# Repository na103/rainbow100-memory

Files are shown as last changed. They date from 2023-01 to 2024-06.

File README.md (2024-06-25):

# Rainbow 100B memory extension
this is a remake of RAM expansion board for [Digital Rainbow 100](https://en.wikipedia.org/wiki/Rainbow_100) rev B<br>

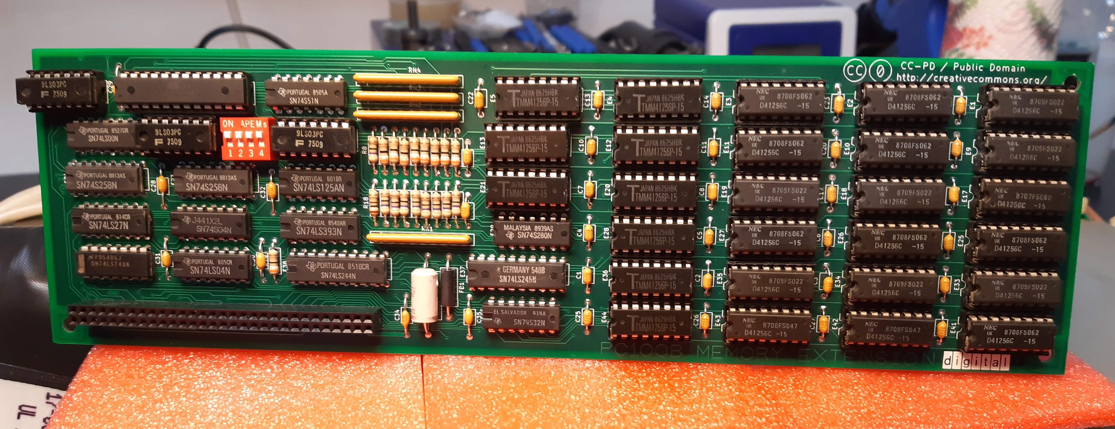
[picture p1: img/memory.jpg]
memory extension


This expansion board it can reach up to 896Kb of RAM. differently to 8088 XT PCs, Rainbow 100 architecture is not limited at 640Kb of memory.<br>
Kicad schematics is derived from [Tony Duell's notes](https://github.com/na103/rainbow100-memory/blob/main/docs/Duell_ram_expansion.pdf) and at the end verified with [original DEC schematics](https://github.com/na103/rainbow100-memory/tree/main/docs/Dec).<br>
95% of the components and traces have been rebuilt respecting the original position; only the bipolar Prom E7 whos entrusted control logic for the memory banks switch has been replaced with a extra large GAL22V10.

## Bill of materials
| Qt. | Description | Designator | Mouser Part | Note |
|:---:|---|---|---|---|
|27 |Cap. 220 nF 50V |C1 -C27 |C430C224Z5U5TA | |
|1 |Cap. 10uF 35V |C33 |MAL213831109E3 | |
|5 |Cap. 47nF 50V |C28 - C32 |C410C473Z5U5TA | |
|2 |Cap. 10nF 50V |C34 C35 |C410C103Z5U5TA | |
|1 |Bead Ferrite |FB1 |2743002112 | |
|1 |Rnet 9x470Ω 10 pin  |RN4 |4610X-101-471LF | |
|2 |Rnet 9x1kΩ 10 pin |RN3 RN2 |4610X-101-102LF | |
|1 |Rnet 9x4.7kΩ 10 pin |RN1 |4610X-AP1-472LF | |
|9 |R 39Ω |R10 - R17 R19 |CFR-25JB-52-39R | |
|1 |R 100Ω |R18 |CFR-25JT-52-100R | |
|9 |R 47Ω |R1 - R9 |CFR-25JB-52-47R | |
|1 |Switch DIP 4POS |SW1 |78RB04ST | |
|1 |025X025 REC 2X30P |J1 |5-102766-4 | |
|27 |16P DIP SKT |E1-E5 E9-E13 E17-E21 E25-E28 |1-2199298-4 | |
| | |E33-E36 E41-E44 | | |
|1 |24P DIP SKT |E7 |1-2199298-8 | optional, useful for testing  |
|1 |GAL 22V10 |E7 |ATF22V10C-15PU | need programmer like TL866 |
|3 |74S03N |E8 E14 E15 |SN74LS03N | |
|1 |74LS00N |E16 |SN74LS00N | |
|2 |74S258N |E23 E24 |SN74LS258N | |
|1 |74LS27N |E32 |SN74LS27N | |
|1 |74LS74AN |E40 |SN74LS74AN | |
|2 |74LS04N |E31 E39 |SN74LS04N | |
|1 |74S51N |E6 |SN74LS51N | |
|1 |74LS125AN |E22 |SN74LS125AN | |
|1 |74LS393N |E30 |SN74LS393N | |
|1 |74LS244N |E38 |SN74LS244N | |
|1 |74S280N |E29 |SN74LS280N | |
|1 |74LS245N |E37 |SN74LS245N | |
|1 |74S32N |E45 |SN74LS32N | |
|27 |DRAM 41256-15 or |E1-E5 E9-13 E17-E21 E25-E28 | | from ebay or [utsource](https://www.utsource.net)|
| |4164-15 max 150ns |E33-E36 E41-E44 | | |
<br><br>
## Memory dip switch set-up

The DIP switches are to be set according to how many banks are populated and with kind of DRAM chip (256kb or 64kb).

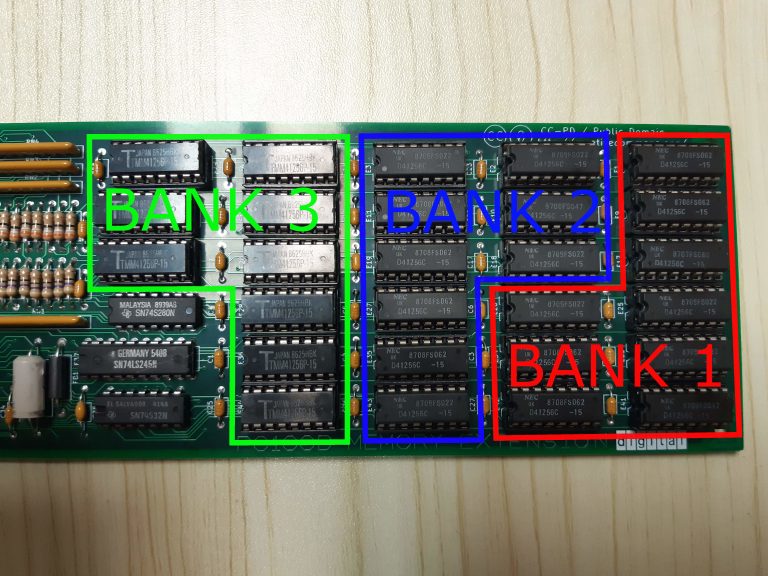
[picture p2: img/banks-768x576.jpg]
banks position


| Dip 1-2-3-4 | bank1 | bank2 | bank3 |
|:---:|---|---|---|
| off off off on | 64K | | |
| off off off on | 64K | 64K | |
| off off off on | 64K | 64K | 64K |
| on  off off on | 256K | 64K or empty | 64K or empty |
| on  on  off on | 256K | 256K | 64K or empty |
| on  on  on  on | 256K | 256K | 256K |

## Building notes

due to the E7 larger size all memory banks are closer to the edge of the board, the two plastic supports need to be filed slightly to get them into their seat
<br>

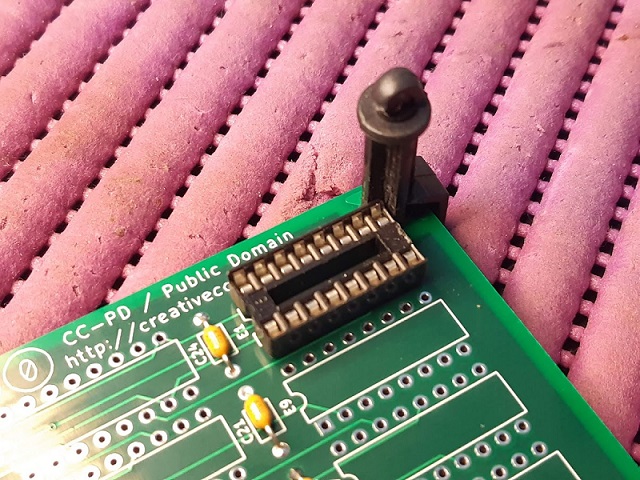
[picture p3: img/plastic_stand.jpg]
stand support

<br>

If you found this my work useful, please consider buying me a cup of coffee if you want:<br>


# License

This work is licensed under a Creative Commons Attribution 4.0 International License. See [https://creativecommons.org/licenses/by/4.0/](https://creativecommons.org/licenses/by/4.0/).

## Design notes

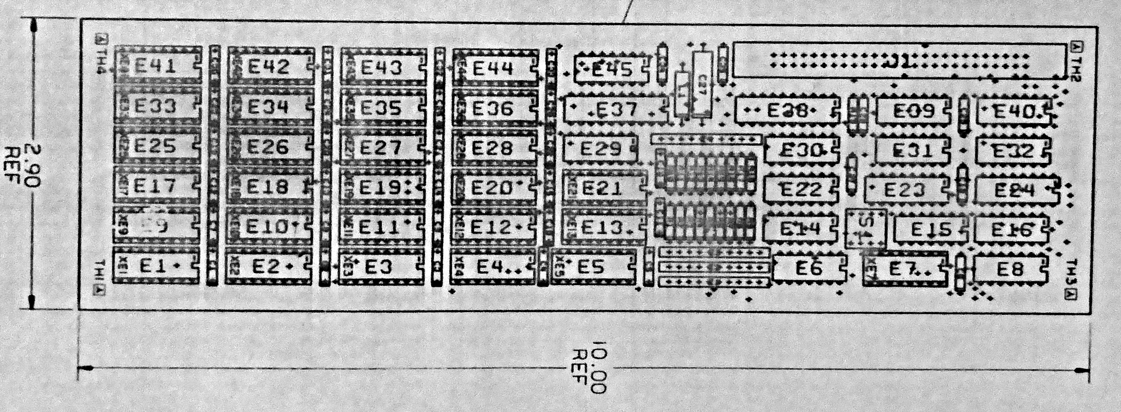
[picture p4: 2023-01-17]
docs/Dec/PC100Bmem 10a P1100113.JPG

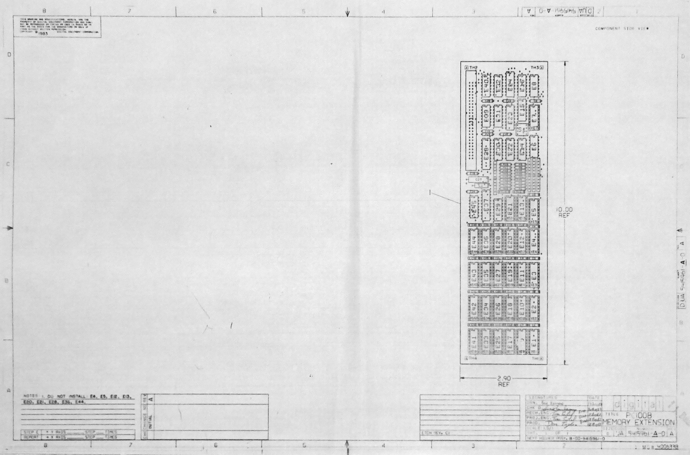
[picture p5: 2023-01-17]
docs/Dec/PC100Bmem 10 P1100112.JPG

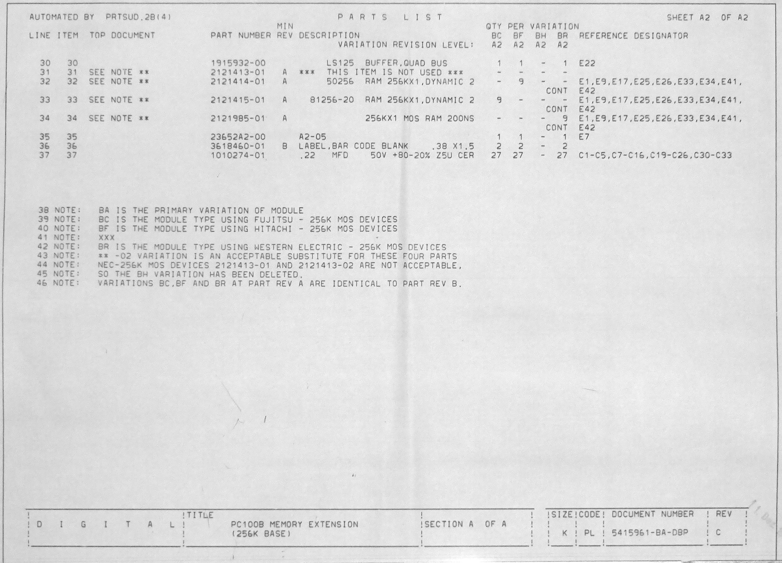
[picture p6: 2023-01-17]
docs/Dec/PC100Bmem 09 P1100109.JPG

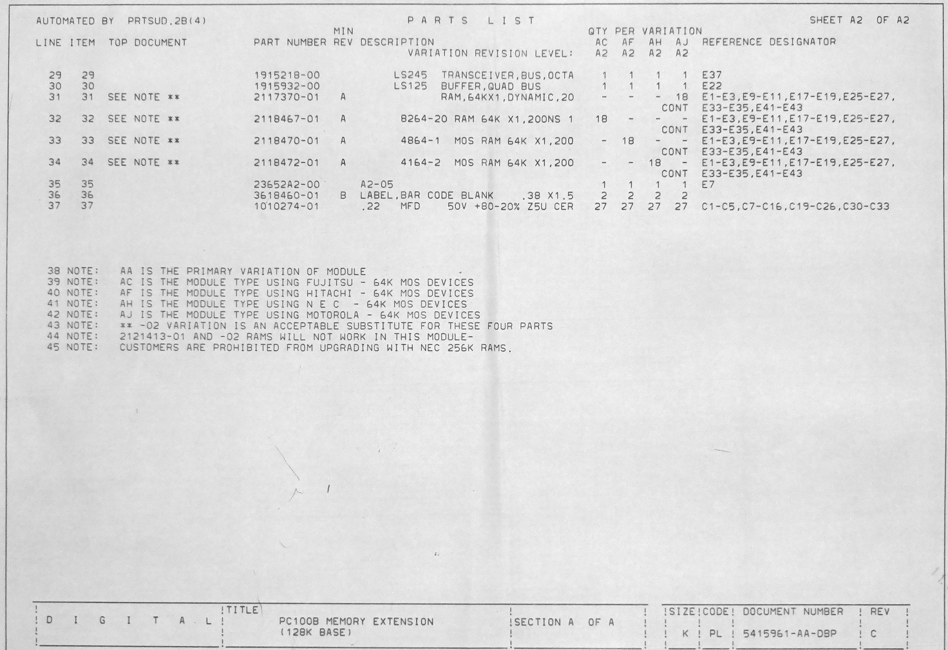
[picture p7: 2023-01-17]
docs/Dec/PC100Bmem 07 P1100106.JPG

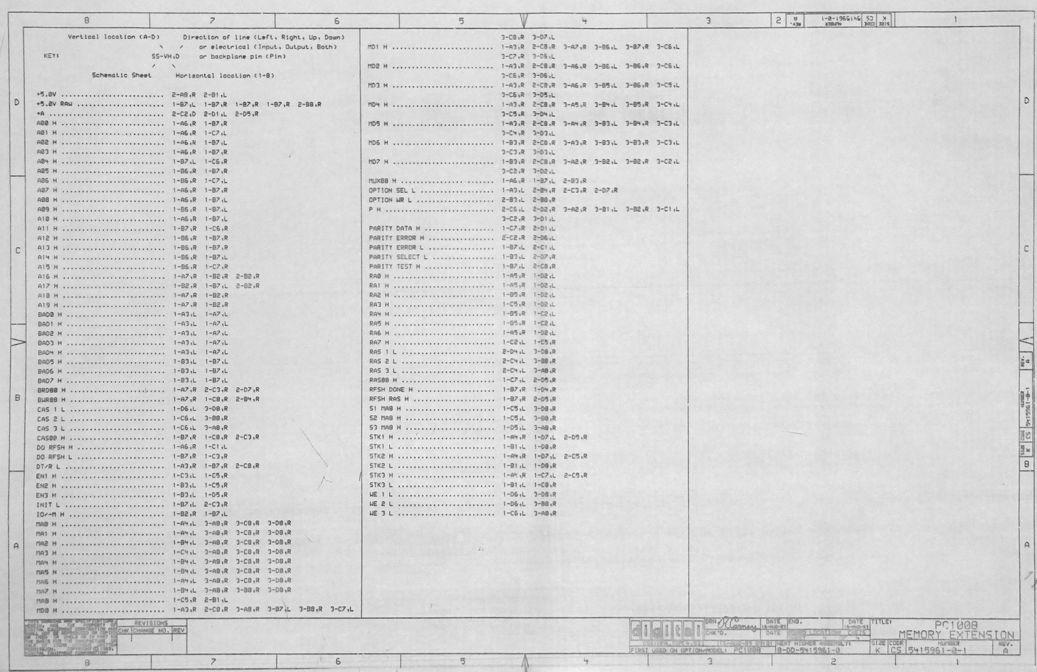
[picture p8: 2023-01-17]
docs/Dec/PC100Bmem 04 P1100098.JPG

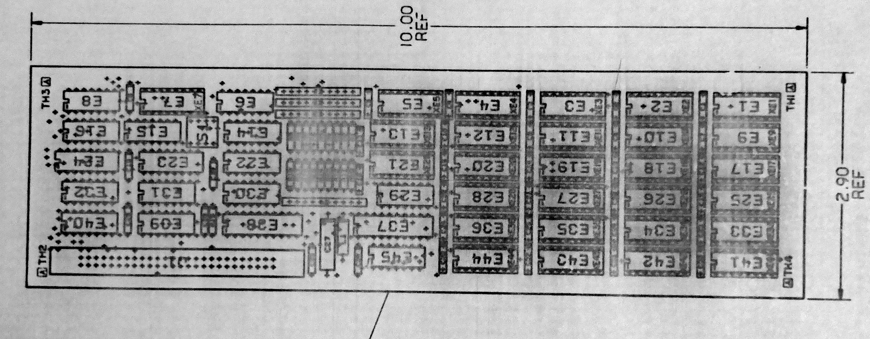
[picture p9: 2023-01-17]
docs/Dec/PC100Bmem 05a P1100102.JPG

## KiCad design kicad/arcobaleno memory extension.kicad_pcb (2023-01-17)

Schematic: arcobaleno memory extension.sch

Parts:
C1, C2, C3, C4, C5, C6, C7, C8, C9, C10, C11, C12, C13, C14, C15, C16, C17, C18, C19, C20, C21, C22, C23, C24, C25, C26, C27: 220nF; C_Axial_L3.8mm_D2.6mm_P7.50mm_Horizontal
C28, C29, C30, C31, C32: 47nF; C_Axial_L3.8mm_D2.6mm_P10.00mm_Horizontal
C33: 10uF; C_Axial_L12.0mm_D6.5mm_P20.00mm_Horizontal
C34, C35: 10nF; C_Axial_L3.8mm_D2.6mm_P10.00mm_Horizontal
E1, E2, E3, E4, E5, E9, E10, E11, E12, E13, E17, E18, E19, E20, E21, E25, E26, E27, E28, E33, E34, E35, E36, E41, E42, E43, E44: UPD41256C; DIP-16_W7.62mm; Manufacturer_Part_Number UPD41256C
E6: 74LS51; DIP-14_W7.62mm
E7: GAL22V10D-15LP; DIP-24_W7.62mm; Mouser Part Number 842-GAL22V10D15LP
E8, E14, E15: 74LS03; DIP-14_W7.62mm
E16: 74LS00; DIP-14_W7.62mm
E22: 74LS125; DIP-14_W7.62mm
E23, E24: 74LS258; DIP-16_W7.62mm
E29: 74LS280; DIP-14_W7.62mm
E30: 74LS393; DIP-14_W7.62mm
E31, E39: 74LS04; DIP-14_W7.62mm
E32: 74LS27; DIP-14_W7.62mm
E37: 74LS245; DIP-20_W7.62mm
E38: 74LS244; DIP-20_W7.62mm
E40: 74LS74; DIP-14_W7.62mm
E45: 74LS32; DIP-14_W7.62mm
FB1: 3 Omh 2.4 uH; L_Axial_L9.5mm_D4.0mm_P15.24mm_Horizontal_Fastron_SMCC
J1: SSW-126-01-T-D; SAMTEC_SSW-126-01-T-D; Mouser Part Number 200-SSW12601TD
R1, R2, R3, R4, R5, R6, R7, R8, R9: 47; R_Axial_DIN0207_L6.3mm_D2.5mm_P10.16mm_Horizontal
R10, R11, R12, R13, R14, R15, R16, R17, R19: 39; R_Axial_DIN0207_L6.3mm_D2.5mm_P10.16mm_Horizontal
R18: 100; R_Axial_DIN0207_L6.3mm_D2.5mm_P10.16mm_Horizontal
RN1: 4.7k; R_Array_SIP10
RN2, RN3: 1k; R_Array_SIP10
RN4: 470; R_Array_SIP10
SW1: SW_DIP_x04

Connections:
+5V: C1.2, C2.2, C3.2, C4.2, C5.2, C6.2, C7.2, C8.2, C9.2, C10.2, C11.2, C12.2, C13.2, C14.2, C15.2, C16.2, C17.2, C18.2, C19.2, C20.2, C21.2, C22.2, C23.2, C24.2, C25.2, C26.2, C27.2, C28.1, C29.1, C30.1, C31.1, C32.1, C33.1, C34.2, C35.1, E1.8 (VCC), E2.8 (VCC), E3.8 (VCC), E4.8 (VCC), E5.8 (VCC), E6.14 (VCC), E7.24 (VCC), E8.14 (VCC), E9.8 (VCC), E10.8 (VCC), E11.8 (VCC), E12.8 (VCC), E13.8 (VCC), E14.14 (VCC), E15.14 (VCC), E16.14 (VCC), E17.8 (VCC), E18.8 (VCC), E19.8 (VCC), E20.8 (VCC), E21.8 (VCC), E22.14 (VCC), E23.16 (VCC), E24.16 (VCC), E25.8 (VCC), E26.8 (VCC), E27.8 (VCC), E28.8 (VCC), E29.14 (VCC), E30.14 (VCC), E31.14 (VCC), E32.14 (VCC), E33.8 (VCC), E34.8 (VCC), E35.8 (VCC), E36.8 (VCC), E37.20 (VCC), E38.20 (VCC), E39.14 (VCC), E40.14 (VCC), E41.8 (VCC), E42.8 (VCC), E43.8 (VCC), E44.8 (VCC), E45.14 (VCC), FB1.1, FB1.2, J1.25, J1.27, J1.28, J1.35, RN1.1 (common), RN2.1 (R1.1), RN3.1 (R1.1), RN4.1 (R1.1)
/MUXA0: E23.12 (Zc), E38.18 (O0a), R17.2, RN2.3 (R2.2)
/MUXA1: E23.9 (Zd), E38.16 (O1a), R16.2, RN2.4 (R3.2)
/MUXA2: E23.4 (Za), E38.14 (O2a), R14.2, RN2.5 (R4.2)
/MUXA3: E24.4 (Za), E38.9 (O0b), R10.2, RN2.6 (R5.2)
/MUXA4: E24.12 (Zc), E38.3 (O3b), R13.2, RN2.7 (R6.2)
/MUXA5: E24.9 (Zd), E38.5 (O2b), R12.2, RN2.8 (R7.2)
/MUXA6: E23.7 (Zb), E38.12 (O3a), R15.2, RN2.9 (R8.2)
/MUXA7: E24.7 (Zb), E38.7 (O1b), R11.2, RN2.10 (R9.2)
/Rfsh0: E30.3 (Q0), E38.2 (I0a)
/Rfsh1: E30.4 (Q1), E38.4 (I1a)
/Rfsh2: E30.5 (Q2), E38.6 (I2a)
/Rfsh3: E30.6 (Q3), E30.13 (CP), E38.11 (I0b)
/Rfsh4: E30.11 (Q0), E38.17 (I3b)
/Rfsh5: E30.10 (Q1), E38.15 (I2b)
/Rfsh6: E30.9 (Q2), E38.8 (I3a)
/Rfsh7: E30.8 (Q3), E38.13 (I1b)
A0: E23.13 (I1c), J1.13
A1: E23.10 (I1d), J1.8
A2: E23.3 (I1a), J1.16
A3: E23.6 (I1b), J1.11
A4: E24.3 (I1a), J1.22
A5: E24.13 (I1c), J1.17
A6: E24.10 (I1d), J1.6
A7: E23.14 (I0c), J1.15
A8: E23.11 (I0d), J1.10
A9: E23.2 (I0a), J1.18
A10: E23.5 (I0b), J1.12
A11: E24.2 (I0a), J1.21
A12: E24.14 (I0c), J1.19
A13: E24.11 (I0d), J1.9
A14: E24.5 (I0b), J1.14
A15: E24.6 (I1b), J1.7
A16: E6.3, E7.9 (I_8), J1.47
A17: E6.5, E7.8 (I_7), J1.32
A18: E7.7 (I_6), J1.43
A19: E7.6 (I_5), J1.49, RN3.2 (R1.2)
AMUX: E6.2, E23.1 (S), E24.1 (S), E31.9, J1.20
CAS1: E1.15 (~CAS), E9.15 (~CAS), E17.15 (~CAS), E25.15 (~CAS), E26.15 (~CAS), E33.15 (~CAS), E34.15 (~CAS), E41.15 (~CAS), E42.15 (~CAS), R9.1
CAS2: E2.15 (~CAS), E3.15 (~CAS), E10.15 (~CAS), E11.15 (~CAS), E18.15 (~CAS), E19.15 (~CAS), E27.15 (~CAS), E35.15 (~CAS), E43.15 (~CAS), R2.1
CAS3: E4.15 (~CAS), E5.15 (~CAS), E12.15 (~CAS), E13.15 (~CAS), E20.15 (~CAS), E21.15 (~CAS), E28.15 (~CAS), E36.15 (~CAS), E44.15 (~CAS), R5.1
CASTime: E8.5, E8.13, E14.10, E16.4, J1.37
ClkParity: E22.8, E40.3 (C), E40.11 (C), RN3.6 (R5.2)
D0: E37.18 (B0), J1.50
D1: E37.17 (B1), J1.48
D2: E37.16 (B2), J1.46
D3: E37.15 (B3), J1.44
D4: E37.14 (B4), J1.42
D5: E37.13 (B5), J1.40
D6: E37.12 (B6), J1.38
D7: E37.11 (B7), J1.36
DRAMA0: E1.5 (A0), E2.5 (A0), E3.5 (A0), E4.5 (A0), E5.5 (A0), E9.5 (A0), E10.5 (A0), E11.5 (A0), E12.5 (A0), E13.5 (A0), E17.5 (A0), E18.5 (A0), E19.5 (A0), E20.5 (A0), E21.5 (A0), E25.5 (A0), E26.5 (A0), E27.5 (A0), E28.5 (A0), E33.5 (A0), E34.5 (A0), E35.5 (A0), E36.5 (A0), E41.5 (A0), E42.5 (A0), E43.5 (A0), E44.5 (A0), R17.1
DRAMA1: E1.7 (A1), E2.7 (A1), E3.7 (A1), E4.7 (A1), E5.7 (A1), E9.7 (A1), E10.7 (A1), E11.7 (A1), E12.7 (A1), E13.7 (A1), E17.7 (A1), E18.7 (A1), E19.7 (A1), E20.7 (A1), E21.7 (A1), E25.7 (A1), E26.7 (A1), E27.7 (A1), E28.7 (A1), E33.7 (A1), E34.7 (A1), E35.7 (A1), E36.7 (A1), E41.7 (A1), E42.7 (A1), E43.7 (A1), E44.7 (A1), R16.1
DRAMA2: E1.6 (A2), E2.6 (A2), E3.6 (A2), E4.6 (A2), E5.6 (A2), E9.6 (A2), E10.6 (A2), E11.6 (A2), E12.6 (A2), E13.6 (A2), E17.6 (A2), E18.6 (A2), E19.6 (A2), E20.6 (A2), E21.6 (A2), E25.6 (A2), E26.6 (A2), E27.6 (A2), E28.6 (A2), E33.6 (A2), E34.6 (A2), E35.6 (A2), E36.6 (A2), E41.6 (A2), E42.6 (A2), E43.6 (A2), E44.6 (A2), R14.1
DRAMA3: E1.12 (A3), E2.12 (A3), E3.12 (A3), E4.12 (A3), E5.12 (A3), E9.12 (A3), E10.12 (A3), E11.12 (A3), E12.12 (A3), E13.12 (A3), E17.12 (A3), E18.12 (A3), E19.12 (A3), E20.12 (A3), E21.12 (A3), E25.12 (A3), E26.12 (A3), E27.12 (A3), E28.12 (A3), E33.12 (A3), E34.12 (A3), E35.12 (A3), E36.12 (A3), E41.12 (A3), E42.12 (A3), E43.12 (A3), E44.12 (A3), R10.1
DRAMA4: E1.11 (A4), E2.11 (A4), E3.11 (A4), E4.11 (A4), E5.11 (A4), E9.11 (A4), E10.11 (A4), E11.11 (A4), E12.11 (A4), E13.11 (A4), E17.11 (A4), E18.11 (A4), E19.11 (A4), E20.11 (A4), E21.11 (A4), E25.11 (A4), E26.11 (A4), E27.11 (A4), E28.11 (A4), E33.11 (A4), E34.11 (A4), E35.11 (A4), E36.11 (A4), E41.11 (A4), E42.11 (A4), E43.11 (A4), E44.11 (A4), R13.1
DRAMA5: E1.10 (A5), E2.10 (A5), E3.10 (A5), E4.10 (A5), E5.10 (A5), E9.10 (A5), E10.10 (A5), E11.10 (A5), E12.10 (A5), E13.10 (A5), E17.10 (A5), E18.10 (A5), E19.10 (A5), E20.10 (A5), E21.10 (A5), E25.10 (A5), E26.10 (A5), E27.10 (A5), E28.10 (A5), E33.10 (A5), E34.10 (A5), E35.10 (A5), E36.10 (A5), E41.10 (A5), E42.10 (A5), E43.10 (A5), E44.10 (A5), R12.1
DRAMA6: E1.13 (A6), E2.13 (A6), E3.13 (A6), E4.13 (A6), E5.13 (A6), E9.13 (A6), E10.13 (A6), E11.13 (A6), E12.13 (A6), E13.13 (A6), E17.13 (A6), E18.13 (A6), E19.13 (A6), E20.13 (A6), E21.13 (A6), E25.13 (A6), E26.13 (A6), E27.13 (A6), E28.13 (A6), E33.13 (A6), E34.13 (A6), E35.13 (A6), E36.13 (A6), E41.13 (A6), E42.13 (A6), E43.13 (A6), E44.13 (A6), R15.1
DRAMA7: E1.9 (A7), E2.9 (A7), E3.9 (A7), E4.9 (A7), E5.9 (A7), E9.9 (A7), E10.9 (A7), E11.9 (A7), E12.9 (A7), E13.9 (A7), E17.9 (A7), E18.9 (A7), E19.9 (A7), E20.9 (A7), E21.9 (A7), E25.9 (A7), E26.9 (A7), E27.9 (A7), E28.9 (A7), E33.9 (A7), E34.9 (A7), E35.9 (A7), E36.9 (A7), E41.9 (A7), E42.9 (A7), E43.9 (A7), E44.9 (A7), R11.1
DRAMD0: E29.9 (B), E34.2 (DIN), E34.14 (DOUT), E35.2 (DIN), E35.14 (DOUT), E36.2 (DIN), E36.14 (DOUT), E37.2 (A0), RN1.3 (R2)
DRAMD1: E26.2 (DIN), E26.14 (DOUT), E27.2 (DIN), E27.14 (DOUT), E28.2 (DIN), E28.14 (DOUT), E29.10 (C), E37.3 (A1), RN1.4 (R3)
DRAMD2: E19.2 (DIN), E19.14 (DOUT), E20.2 (DIN), E20.14 (DOUT), E29.11 (D), E37.4 (A2), E41.2 (DIN), E41.14 (DOUT), RN1.5 (R4)
DRAMD3: E11.2 (DIN), E11.14 (DOUT), E12.2 (DIN), E12.14 (DOUT), E29.12 (E), E33.2 (DIN), E33.14 (DOUT), E37.5 (A3), RN1.6 (R5)
DRAMD4: E3.2 (DIN), E3.14 (DOUT), E4.2 (DIN), E4.14 (DOUT), E25.2 (DIN), E25.14 (DOUT), E29.13 (F), E37.6 (A4), RN1.7 (R6)
DRAMD5: E17.2 (DIN), E17.14 (DOUT), E18.2 (DIN), E18.14 (DOUT), E21.2 (DIN), E21.14 (DOUT), E29.1 (G), E37.7 (A5), RN1.8 (R7)
DRAMD6: E9.2 (DIN), E9.14 (DOUT), E10.2 (DIN), E10.14 (DOUT), E13.2 (DIN), E13.14 (DOUT), E29.2 (H), E37.8 (A6), RN1.9 (R8)
DRAMD7: E1.2 (DIN), E1.14 (DOUT), E2.2 (DIN), E2.14 (DOUT), E5.2 (DIN), E5.14 (DOUT), E29.4 (I), E37.9 (A7), RN1.10 (R9)
DRAMP: E22.3, E22.6, E32.13, E40.2 (D), E42.2 (DIN), E42.14 (DOUT), E43.2 (DIN), E43.14 (DOUT), E44.2 (DIN), E44.14 (DOUT), RN1.2 (R1)
GND: C1.1, C2.1, C3.1, C4.1, C5.1, C6.1, C7.1, C8.1, C9.1, C10.1, C11.1, C12.1, C13.1, C14.1, C15.1, C16.1, C17.1, C18.1, C19.1, C20.1, C21.1, C22.1, C23.1, C24.1, C25.1, C26.1, C27.1, C28.2, C29.2, C30.2, C31.2, C32.2, C33.2, C34.1, C35.2, E1.16 (GND), E2.16 (GND), E3.16 (GND), E4.16 (GND), E5.16 (GND), E6.7 (GND), E7.12 (GND), E8.7 (GND), E9.16 (GND), E10.16 (GND), E11.16 (GND), E12.16 (GND), E13.16 (GND), E14.7 (GND), E15.7 (GND), E16.7 (GND), E17.16 (GND), E18.16 (GND), E19.16 (GND), E20.16 (GND), E21.16 (GND), E22.7 (GND), E23.8 (GND), E24.8 (GND), E25.16 (GND), E26.16 (GND), E27.16 (GND), E28.16 (GND), E29.7 (GND), E30.7 (GND), E31.7 (GND), E32.7 (GND), E33.16 (GND), E34.16 (GND), E35.16 (GND), E36.16 (GND), E37.10 (GND), E38.10 (GND), E39.7 (GND), E40.7 (GND), E41.16 (GND), E42.16 (GND), E43.16 (GND), E44.16 (GND), E45.7 (GND), J1.1, J1.2, J1.3, J1.51, J1.52, R18.2, SW1.1, SW1.2, SW1.3, SW1.4
IO_M: E7.2 (I_1), J1.30
unnamed: E1.1 (A8), E9.1 (A8), E17.1 (A8), E25.1 (A8), E26.1 (A8), E33.1 (A8), E34.1 (A8), E41.1 (A8), E42.1 (A8), E45.8
unnamed: E6.6, R19.2, RN3.8 (R7.2)
unnamed: E8.3, R8.2, RN4.2 (R1.2)
unnamed: E8.6, R9.2, RN4.9 (R8.2)
unnamed: E8.8, R1.2, RN4.5 (R4.2)
unnamed: E8.11, R2.2, RN4.4 (R3.2)
unnamed: E2.1 (A8), E3.1 (A8), E10.1 (A8), E11.1 (A8), E18.1 (A8), E19.1 (A8), E27.1 (A8), E35.1 (A8), E43.1 (A8), E45.6
unnamed: E4.1 (A8), E5.1 (A8), E12.1 (A8), E13.1 (A8), E20.1 (A8), E21.1 (A8), E28.1 (A8), E36.1 (A8), E44.1 (A8), E45.3
unnamed: E14.3, E14.6, R4.2, RN4.7 (R6.2)
unnamed: E14.8, R5.2, RN4.8 (R7.2)
unnamed: E14.11, R6.2, RN4.10 (R9.2)
unnamed: E14.5, E14.9, E14.12, E31.4, E32.11
unnamed: E15.3, E15.6, R7.2, RN4.3 (R2.2)
unnamed: E8.2, E8.4, E15.5, E31.2, E32.9
unnamed: E8.10, E8.12, E15.9, E31.10, E32.10
unnamed: E15.8, E15.11, R3.2, RN4.6 (R5.2)
unnamed: E16.1, E22.12, E39.8
unnamed: E16.2, E39.6
unnamed: E16.3, E22.1
unnamed: E16.6, E22.9
unnamed: E16.8, E39.11
unnamed: E16.9, E16.11, E22.13
unnamed: E16.12, E39.12
unnamed: E22.2, E29.5 (Even), E32.5
unnamed: E22.5, E29.6 (Odd)
unnamed: E22.4, E22.11, RN3.5 (R4.2)
unnamed: E23.15 (OE), E24.15 (OE), E31.6
unnamed: E29.8 (A), E32.12
unnamed: E30.2 (MR), E30.12 (MR), R18.1
unnamed: E7.23 (I/O/Q_10), E31.1
unnamed: E7.16 (I/O/Q_3), E31.3
unnamed: E6.4, E31.8
unnamed: E7.22 (I/O/Q_9), E31.11
unnamed: E32.1, E39.2
unnamed: E32.4, RN3.9 (R8.2), SW1.5
unnamed: E32.6, E40.12 (D)
unnamed: E39.10, E40.1 (~R), E40.13 (~R)
unnamed: E7.5 (I_4), E45.1, RN3.7 (R6.2), SW1.6
unnamed: E45.2, E45.5, E45.9, R19.1
unnamed: E7.4 (I_3), E45.4, RN3.4 (R3.2), SW1.7
unnamed: E7.3 (I_2), E45.10, RN3.3 (R2.2), SW1.8
PUI: E14.1, E15.1, E15.13, E40.4 (~S), E40.10 (~S), RN2.2 (R1.2)
ParityCtrl: E39.9, J1.24
ParityOut: E40.5 (Q), J1.5
RAS1: E1.4 (~RAS), E9.4 (~RAS), E17.4 (~RAS), E25.4 (~RAS), E26.4 (~RAS), E33.4 (~RAS), E34.4 (~RAS), E41.4 (~RAS), E42.4 (~RAS), R7.1
RAS2: E2.4 (~RAS), E3.4 (~RAS), E10.4 (~RAS), E11.4 (~RAS), E18.4 (~RAS), E19.4 (~RAS), E27.4 (~RAS), E35.4 (~RAS), E43.4 (~RAS), R3.1
RAS3: E4.4 (~RAS), E5.4 (~RAS), E12.4 (~RAS), E13.4 (~RAS), E20.4 (~RAS), E21.4 (~RAS), E28.4 (~RAS), E36.4 (~RAS), E44.4 (~RAS), R4.1
RASTime: E14.4, E15.4, E15.10, J1.4
RD: E16.5, E39.1, J1.41
RfshInc: E30.1 (CP), J1.33
RfshRAS: E14.2, E15.2, E15.12, J1.23
WR: E8.1, E8.9, E14.13, E16.13, J1.45
WR1: E1.3 (~WE), E9.3 (~WE), E17.3 (~WE), E25.3 (~WE), E26.3 (~WE), E33.3 (~WE), E34.3 (~WE), E41.3 (~WE), E42.3 (~WE), R8.1
WR2: E2.3 (~WE), E3.3 (~WE), E10.3 (~WE), E11.3 (~WE), E18.3 (~WE), E19.3 (~WE), E27.3 (~WE), E35.3 (~WE), E43.3 (~WE), R1.1
WR3: E4.3 (~WE), E5.3 (~WE), E12.3 (~WE), E13.3 (~WE), E20.3 (~WE), E21.3 (~WE), E28.3 (~WE), E36.3 (~WE), E44.3 (~WE), R6.1
_BuffEn: E22.10, E32.2, E32.3, E32.8, E37.19 (CE), E39.13
_DT_R: E37.1 (A->B), E39.5, J1.39
_NMI: E40.8 (~Q), J1.26
_RST: E16.10, J1.34
_RfshAddr: E31.5, E38.1 (OEa), E38.19 (OEb), J1.31

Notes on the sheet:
Refresh Counter
BANK SELECT
Data Buffer and Parity
BankEn1
BankEn2
BankEn3
When the PC 100-B memory extension option is installed, address bit 18 is used in conjunction with address bits 16, 17, and 19 to select the memory stack.
The status of this input signal determines which set of four signals are used to select the memory banks in the PC100-A or PC100-B memory extension options. If a PC100-A memory option is installed, the signal is ground. If a PC 100-B memory option is installed, this signal is high.
When a PC 100-A memory option is installed, NONSHRCYC is asserted low cycle to enable memory option accesses. When a PC 100-B memory option is installed, the 8088 processor asserts 10/M low to enable memory option accesses.
BANK ENABLE
BANK 1
BANK 2
BANK 3
The switch labeled '4' is easy. It must always be ON. Switches 1 through 3 correspond to memory banks 1 through 3, respectively. If a memory bank contains 256k chips, then the corresponding switch must be ON. Likewise, if a memory bank contains 64k chips, the corresponding switch must be OFF. If a 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
BANK1
BANK2
BANK3
RAM Address

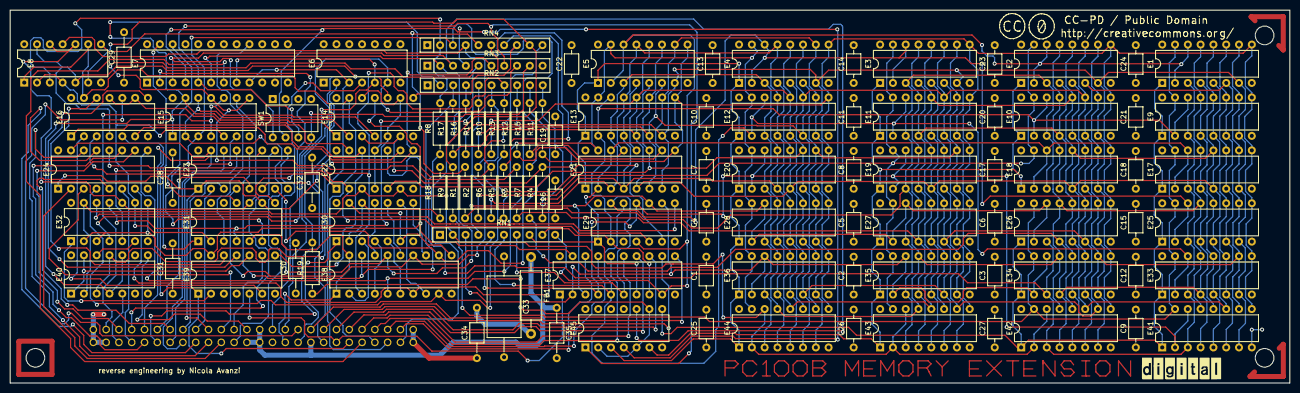
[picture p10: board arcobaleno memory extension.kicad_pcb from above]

Board: 4 copper layers, 254.0 x 74.0 mm, 106 parts (1 on the bottom side), 130 nets.

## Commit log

2023-01-17 Duell and DEC schematics
2023-01-17 Kicad project with gerber
    [arcobaleno memory extension-B_Cu.gbl, arcobaleno memory extension-B_Mask.gbs, arcobaleno memory extension-B_Paste.gbp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]
2023-01-17 switch and ram setup
